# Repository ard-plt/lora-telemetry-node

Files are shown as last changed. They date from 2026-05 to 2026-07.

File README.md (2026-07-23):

# LoRa Telemetry Node

An end-to-end telemetry link that reads MAVLink 2 data from a Pixhawk over
UART, packs it into a compact binary frame, encrypts it, and relays it over
a long-range 868 MHz LoRa link to a ground station running QGroundControl.

```
[Pixhawk TELEM2] --UART MAVLink2--> [ESP32-S3 TX Node] --LoRa 868MHz--> [ESP32-S3 RX Node] --USB--> [QGroundControl]
```

The ESP32 does not read any sensors itself — Pixhawk is the only data
source. The TX node parses MAVLink, serializes + encrypts a fixed-size
packet, and transmits it over LoRa; the RX node decrypts and re-emits it
as MAVLink 2 over USB so QGroundControl sees a normal telemetry stream.

## LoRa Module

Both nodes use an **EBYTE E22-900T30D** (SX1262, 868 MHz, up to 30 dBm)
LoRa transceiver module, talking to the ESP32 over UART in the module's
Normal (transparent) mode.

| Parameter | Value |
|---|---|
| Frequency | 868.0 MHz |
| Spreading Factor | SF9 |
| Bandwidth | 125 kHz |
| Coding Rate | 4/5 |
| TX Power | 30 dBm |
| Air Data Rate | selectable, 0.3–62.5 kbps (see below) |

**Power warning:** the E22-900T30D draws up to ~500 mA while transmitting.
Do **not** power it from the ESP32's own 3.3 V regulator — use a dedicated
AMS1117-3.3 LDO (1 A rated), with a shared ground between the ESP32 and
the E22.

### Bridge Mode + Air Data Rate

Each node can run in one of two modes, selected (along with the LoRa air
data rate) from a web configuration panel rather than a physical switch:

- **BRIDGE_TRANSPARENT** — the node becomes a transparent UART bridge so
  Mission Planner can reach the Pixhawk directly through the LoRa link for
  parameter/calibration/waypoint work.
- **BRIDGE_COMPRESSED** — normal telemetry mode: TX parses → packs →
  encrypts → transmits; RX receives → decrypts → unpacks → re-emits
  MAVLink.

| Air Rate | UART Baud |
|---|---|
| 0.3 / 1.2 / 2.4 / 4.8 kbps | 9600 |
| 9.6 kbps | 19200 |
| 19.2 kbps | 38400 |
| 38.4 kbps | 57600 |
| 62.5 kbps | 115200 |

Holding the config button (GPIO9) for 3 seconds opens a WPA2-protected
Wi-Fi access point (`TUAV-TX-Config` / `TUAV-RX-Config`) with a captive
portal for selecting bridge mode, air rate, and Wi-Fi password. Changing
the mode/rate from the **RX** node automatically re-synchronizes the
**TX** node over the RF link itself — no need to configure both ends by
hand. See `CLAUDE.md` for the full protocol details.

## PCB

A complete KiCad 10 PCB design lives under [`hardware/pcb/`](hardware/pcb),
covering both nodes as a two-board stack:

- **`main`** — ESP32-S3-DevKitC-1 socket + power section (UBEC input →
  PTC fuse → reverse-polarity protection → a dedicated buck regulator
  that isolates the E22's transmit current pulses from the ESP32 rail).
  Identical design for both TX and RX; fabricate two copies.
- **`tx_rf`** / **`rx_rf`** — the E22-900T30D module plus node-specific
  connectors (TX: Pixhawk TELEM2 JST-GH; RX: SSD1306 OLED header), on a
  small board that plugs directly onto `main` via a 16-pin header/socket
  (`J4`), stacked so the assembly stays compact.

Each project folder includes the schematic, PCB layout, custom footprint/
symbol libraries, and ready-to-fabricate Gerber + drill files
(`gerbers/`). Signal-net routing is left for completion in the KiCad GUI;
net assignments are DRC-verified and the ratsnest will guide it.

| Board | Size |
|---|---|
| `main` | 50 × 71 mm |
| `tx_rf` / `rx_rf` | 50 × 60 mm |

## Hardware Overview

| Component | Model |
|---|---|
| MCU | ESP32-S3-WROOM-1 (via ESP32-S3-DevKitC-1), ×2 |
| LoRa module | EBYTE E22-900T30D (SX1262, 868 MHz, 30 dBm) |
| Pixhawk link | TELEM2 → ESP32 UART2, MAVLink 2, 57600 baud |
| Ground station link | RX node's native USB (USB-OTG), 57600 baud — no FT232 needed |
| OLED (RX only) | SSD1306 128×64, I2C |

## Pin Mapping

### TX Node (air)

| Signal | ESP32 Pin |
|---|---|
| E22 TXD | GPIO4 (UART1 RX) |
| E22 RXD | GPIO5 (UART1 TX) |
| E22 AUX | GPIO6 |
| E22 M0 | GPIO7 |
| E22 M1 | GPIO8 |
| Config button | GPIO9 |
| Pixhawk TELEM2 TX | GPIO16 (UART2 RX) |
| Pixhawk TELEM2 RX | GPIO17 (UART2 TX) |

### RX Node (ground)

| Signal | ESP32 Pin |
|---|---|
| E22 TXD | GPIO4 (UART1 RX) |
| E22 RXD | GPIO5 (UART1 TX) |
| E22 AUX | GPIO6 |
| E22 M0 | GPIO7 |
| E22 M1 | GPIO8 |
| Config button | GPIO9 |
| OLED SDA | GPIO11 |
| OLED SCL | GPIO12 |

E22 M0=LOW, M1=LOW selects Normal TX/RX mode (set automatically at boot).
The E22↔ESP32 UART baud follows the selected air data rate (see table
above); the Pixhawk and ground-station links stay fixed at 57600 baud
regardless of LoRa mode.

## Packet Format (40 bytes, plaintext)

| Offset | Len | Type | Field |
|---|---|---|---|
| 0 | 1 | uint8 | header (fixed 0xAD) |
| 1 | 1 | uint8 | seq_id |
| 2 | 4 | int32 | latitude (degE7) |
| 6 | 4 | int32 | longitude (degE7) |
| 10 | 4 | int32 | altitude_mm (MSL) |
| 14 | 2 | int16 | relative_alt_cm |
| 16 | 2 | int16 | groundspeed_cms |
| 18 | 2 | int16 | airspeed_cms |
| 20 | 2 | int16 | heading_cd |
| 22 | 2 | int16 | roll_cd |
| 24 | 2 | int16 | pitch_cd |
| 26 | 2 | int16 | yaw_cd |
| 28 | 2 | int16 | climb_rate_cms |
| 30 | 2 | uint16 | vbat_mv |
| 32 | 2 | int16 | current_da |
| 34 | 2 | uint16 | lidar_cm (0xFFFF = invalid) |
| 36 | 1 | uint8 | battery_pct |
| 37 | 1 | uint8 | flight_mode |
| 38 | 1 | uint8 | armed |
| 39 | 1 | uint8 | checksum (XOR of bytes 0–38) |

## Encryption

Telemetry is encrypted with AES-128-CTR (ESP32 hardware AES accelerator
via mbedTLS) before transmission: 40-byte plaintext → 40-byte ciphertext,
plus an 8-byte nonce (`seq_id` + low bytes of `millis()`) sent alongside
it. The key lives in `common/aes_config.h` as `AES_KEY` — the checked-in
value is a placeholder, **change it before any real deployment**, and
flash both nodes with the same key.

Separately, copy `common/secrets.h.example` to `common/secrets.h` and
fill in your own `WEB_CONFIG_SALT` (generate one with `openssl rand -hex
32`). This salt authenticates the HMAC on the RX→TX mode/rate sync
command over the RF link; `secrets.h` is gitignored and must never be
committed.

## Build & Flash

```bash
pip install platformio

# TX node
cd tx-node && pio run --target upload

# RX node
cd rx-node && pio run --target upload
```

## QGroundControl Setup

Application Settings → Comm Links → Add:
- Type: **Serial**
- Port: the RX node's COM / `ttyACM` port
- Baud rate: **57600**

See [`docs/qgc_setup.md`](docs/qgc_setup.md) for details and
[`docs/breadboard_wiring.md`](docs/breadboard_wiring.md) for a breadboard
wiring guide (or use the PCB design above instead).

## License

MIT

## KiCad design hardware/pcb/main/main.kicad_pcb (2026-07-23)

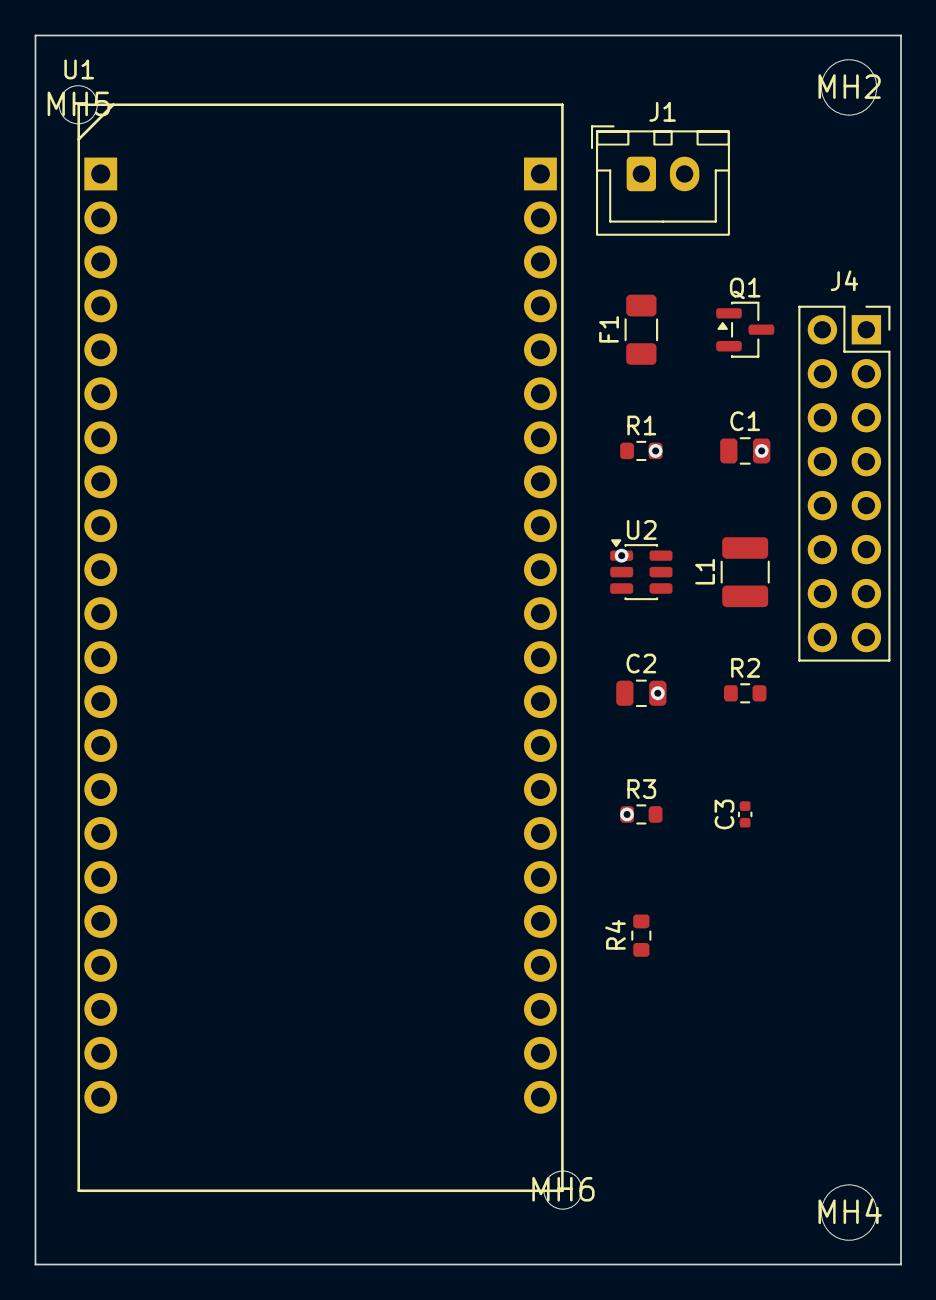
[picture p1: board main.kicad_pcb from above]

Board: 2 copper layers, 50.0 x 71.0 mm, 18 parts (0 on the bottom side), 22 nets, no tracks yet.

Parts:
C1, C2: 22uF; C_0805_2012Metric
C3: 100nF; C_0402_1005Metric
F1: PTC 1.1A; Fuse_1206_3216Metric
J1: VIN_UBEC; JST_XH_B2B-XH-A_1x02_P2.50mm_Vertical
J4: STACK_TO_RF; PinSocket_2x08_P2.54mm_Vertical
L1: 2.2uH; L_1210_3225Metric
MH2, MH4, MH5, MH6: (no value)
Q1: AO3401A; SOT-23
R1, R3: 10k; R_0603_1608Metric
R2: 56k; R_0603_1608Metric
R4: 100k; R_0603_1608Metric
U1: DevKitC-1; ESP32-S3-DevKitC-1_Socket_2x22_P2.54mm
U2: TPS563201; SOT-23-6

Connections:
+3V3: J4.4, U1.J1-1, U1.J1-2
CONFIG_BTN: J4.10, U1.J1-15
E22_AUX: J4.9, U1.J1-6
E22_M0: J4.7, U1.J1-7
E22_M1: J4.8, U1.J1-12
E22_RXD: J4.6, U1.J1-5
E22_SW: C3.2, L1.1, U2.2
E22_TXD: J4.5, U1.J1-4
E22_VCC: C2.1, J4.3, L1.2, R2.2
GND: C1.2, C2.2, J1.2, J4.1, J4.2, J4.16, R1.2, R3.1, U1.J1-22, U1.J3-1, U1.J3-21, U1.J3-22, U2.1
LED_CTRL: J4.11, U1.J3-5
unnamed: C3.1, U2.6
unnamed: R2.1, R3.2, U2.4
unnamed: R4.1, U2.5
OLED_SCL: J4.15, U1.J1-18
OLED_SDA: J4.14, U1.J1-17
PIXHAWK_RX: J4.13, U1.J1-9
PIXHAWK_TX: J4.12, U1.J1-10
Q1_GATE: Q1.1, R1.1
VIN_FUSED: F1.2, Q1.2
VIN_RAW: F1.1, J1.1
VSYS: C1.1, Q1.3, R4.2, U1.J1-21, U2.3

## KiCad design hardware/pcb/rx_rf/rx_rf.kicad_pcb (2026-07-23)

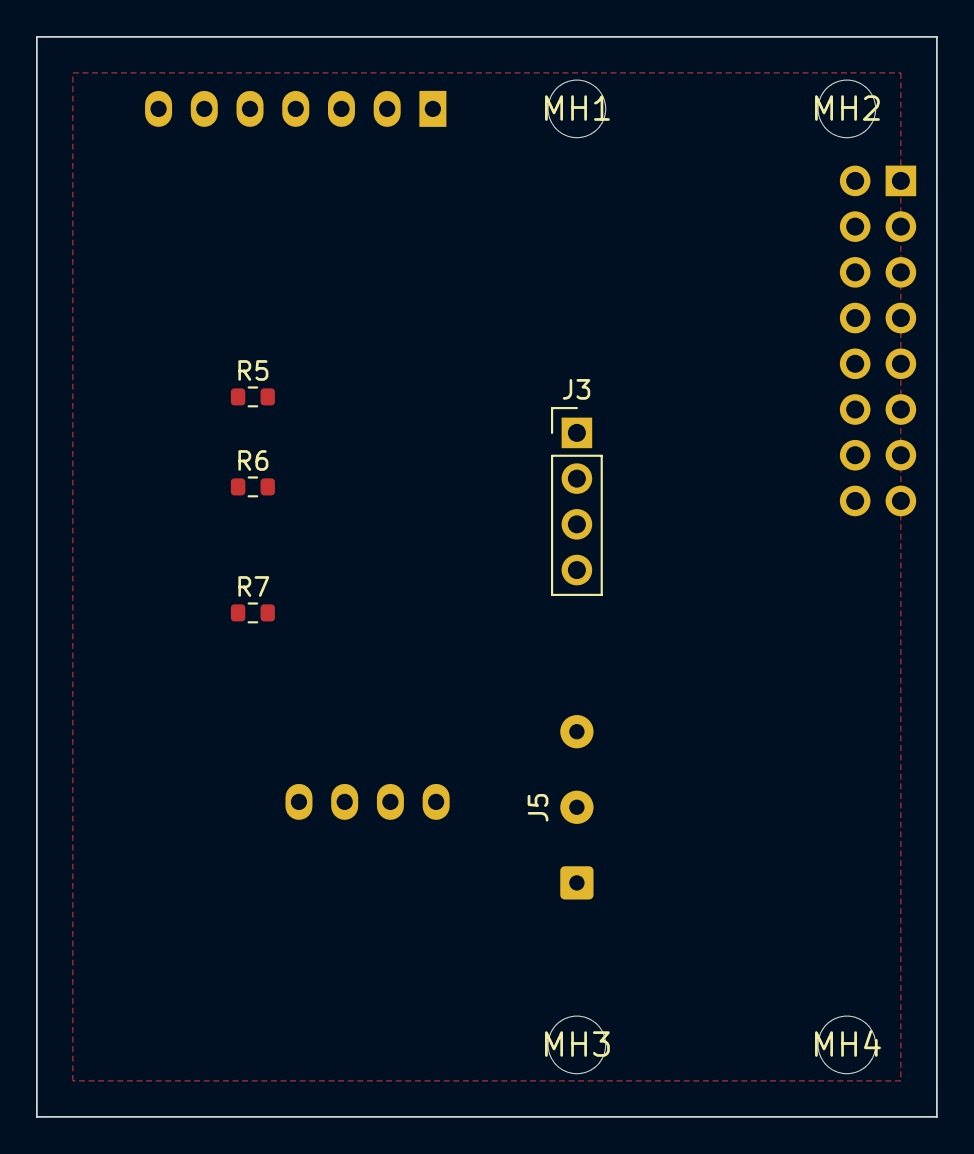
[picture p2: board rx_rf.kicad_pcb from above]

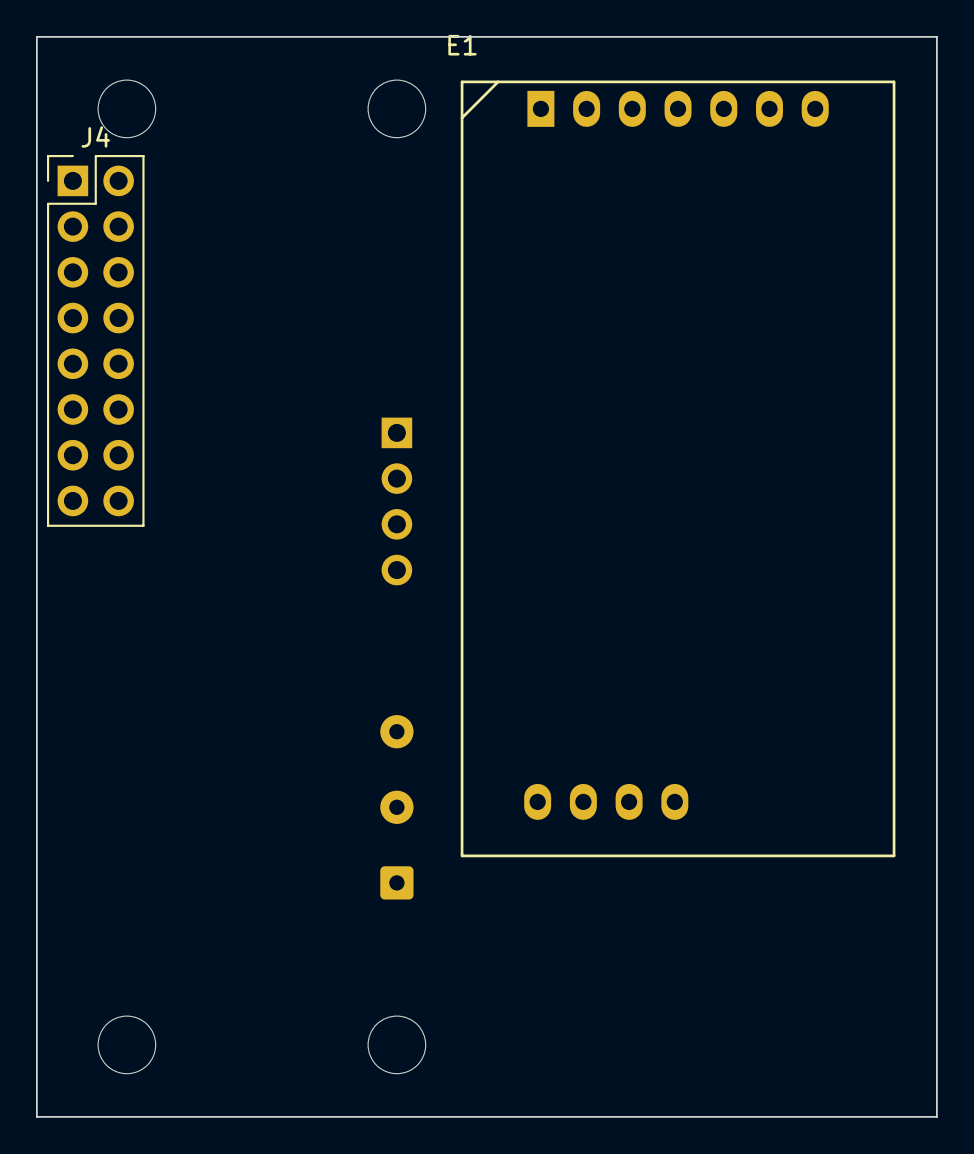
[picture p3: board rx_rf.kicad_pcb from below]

Board: 2 copper layers, 50.0 x 60.0 mm, 11 parts (2 on the bottom side), 13 nets, no tracks yet.

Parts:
E1: E22-900T30D
J3: OLED_SSD1306; PinHeader_1x04_P2.54mm_Vertical
J4: STACK_TO_MAIN; PinHeader_2x08_P2.54mm_Vertical
J5: BTN_LED_REMOTE; SolderWire-0.25sqmm_1x03_P4.2mm_D0.65mm_OD1.7mm
MH1, MH2, MH3, MH4: (no value)
R5, R6: 4.7k; R_0603_1608Metric
R7: 330R; R_0603_1608Metric

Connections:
+3V3: J3.1, J4.4, R5.1, R6.1
CONFIG_BTN: J4.10, J5.1
E22_AUX: E1.5, J4.9
E22_M0: E1.1, J4.7
E22_M1: E1.2, J4.8
E22_RXD: E1.3, J4.6
E22_TXD: E1.4, J4.5
E22_VCC: E1.6, J4.3
GND: E1.7, E1.8, E1.9, E1.10, E1.11, J3.2, J4.1, J4.2, J4.16, J5.2
LED_CTRL: J4.11, R7.1
unnamed: J5.3, R7.2
OLED_SCL: J3.4, J4.15, R6.2
OLED_SDA: J3.3, J4.14, R5.2

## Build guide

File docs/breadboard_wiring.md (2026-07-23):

# Breadboard Bağlantı Rehberi — ESP32 + E22-900T30D

## Önemli: E22 Güç Hattı

E22-900T30D TX anında **~500mA** akım çeker.
ESP32'nin 3.3V pininden BESLEME — E22 VCC direkt ESP32 3V3'e BAĞLAMA.

**Doğru güç yapısı:**
```
USB (5V) veya LiPo
    │
    ├── ESP32 5V (VIN pini) ──→ ESP32 dahili regülatör ──→ ESP32 çalışır
    │
    └── AMS1117-3.3 LDO (ayrı)
            │ IN: 5V
            │ OUT: 3.3V (1A kapasiteli)
            └──→ E22 VCC
                 (GND → ortak GND hattına)
```

Eğer AMS1117 yoksa geçici test için: ESP32 3V3 pininden besle ama
TX gücü maksimum **17 dBm'e düşür** (E22 register ile) — aksi halde
ESP32 regülatörü aşırı ısınır / reset atar.

---

## E22-900T30D Pin Düzeni

E22'nin modül üzerindeki pin sırası (tipik EBYTE layout, 2×8 pin):

```
       [ Anten ]
  ┌─────────────┐
  │  VCC   GND  │
  │  TXD   RXD  │
  │  AUX   M0   │
  │  M1    ...  │
  └─────────────┘
```

> **Datasheet kontrolü:** Elindeki E22'nin üzerindeki pin etiketlerine bak.
> TXD = E22'nin veri çıkışı → ESP32'nin RX pinine bağlanır.
> RXD = E22'nin veri girişi → ESP32'nin TX pinine bağlanır.

---

## Config Butonu + Web UI (KALİBRASYON / UZUN MENZİL)

Her iki node'da E22'nin çalışma modu artık fiziksel bir SPDT switch ile değil,
GPIO9'a bağlı **momentary bir buton** ve buradan açılan bir web arayüzü ile
seçiliyor. GPIO9 `INPUT_PULLUP` olarak ayarlı — harici direnç gerekmez, butonu
doğrudan GPIO9 ↔ GND arasına bağla (basınca kısa devre, bırakınca açık).

| Davranış | Sonuç |
|---|---|
| Normal açılış (buton basılı değil) | NVS'te (`Preferences`) en son kaydedilen mod otomatik uygulanır, WiFi kapalı, LoRa relay loop'u hemen çalışır |
| Buton 3sn basılı tutulur | `WiFi.softAP()` ile WPA2 şifreli config AP'si açılır, captive portal (DNSServer + WebServer) başlar |
| Web UI'de mod seçimi | E22 çalışma zamanında yeniden yapılandırılır (canlı test), NVS'e henüz yazılmaz |
| "Uçuşa Hazır / Kaydet ve Kapat" | Seçili mod NVS'e kaydedilir, AP kapanır, node normal moda döner |
| AP açıkken 5dk hiç istek gelmezse  | AP otomatik kapanır, normal moda döner (watchdog) |

| Mod (BridgeMode)  | Varsayılan E22 UART Baud | Varsayılan Air Rate |
|---|---|---|
| KALİBRASYON (BRIDGE_TRANSPARENT) | 115200 | 62.5kbps |
| UZUN MENZİL (BRIDGE_COMPRESSED)  | 9600 | 2.4kbps  |

KALİBRASYON modunda node transparan köprüye geçer (Mission Planner E22
üzerinden Pixhawk'a doğrudan erişir); UZUN MENZİL modu uçuş sırasında
kullanılacak asıl şifreli telemetri modudur. **Bridge mode (yukarıdaki
tablo) ve air rate artık BAĞIMSIZ seçilir** — web UI'daki air-rate
dropdown'undan 0.3/1.2/2.4/4.8/9.6/19.2/38.4/62.5 kbps arasından herhangi
biri, seçili bridge mode'dan bağımsız olarak seçilebilir; yukarıdaki tablo
sadece hiç değiştirilmemişse (ilk açılış) geçerli varsayılanı gösterir.
**TX ve RX'in konuşabilmesi için ikisinin de aynı air rate'te olması
gerekir** — bu LoRa'nın fiziksel katman kısıtıdır. RX'in web panelinden
yapılan değişiklikler artık TX'i RF üzerinden (ek kablolama YOK — aynı
E22↔E22 telemetri hattı üzerinden) otomatik senkronize eder: RX önce eski
profille bir komut gönderir, TX ACK'lerse RX de kendi profilini uygular; TX
yanıt vermezse (menzil dışı vb.) RX kendi modunu değiştirmez ve panelde
hata gösterir. Ayrıntı ve paket formatı: `common/sync_command.h`,
`rx-node/lib/sync_master/sync_master.h`, ana `CLAUDE.md`'deki **RX-Master
Mod/Rate Senkronizasyonu** bölümü. TX'in panelinden DOĞRUDAN yapılan bir
değişiklik bu mekanizmayı TETİKLEMEZ (RX'e senkronize edilmez). Profil
detayı: `common/lora_modes.h` (`BridgeMode`, `AirRate`,
`lora_build_profile`). Web config paneli detayı: `common/web_config.h` ve
ana `CLAUDE.md`'deki **Web Config Paneli** / **Air Data Rate** bölümleri.

E22 REG1 bit5 (RSSI ambient noise enable, `LORA_REG1_VALUE`) her iki node'da
da her zaman açık tutulur — RX node'un periyodik RSSI sorgusu (bkz. **Link
İstatistikleri & OLED**, aşağıda) bu bite bağımlıdır; TX'te bu bitin bir
etkisi yoktur (zararsız).

**Güvenlik notu:** Config AP'si sadece buton 3sn basılı tutulunca açılır ve
WPA2 ile şifrelidir. Fabrika varsayılan şifresi **tüm cihazlarda aynıdır**
(`tuav-loralink`) — kapalı/kontrollü ortamlarda (TEKNOFEST sahası gibi)
bilinçli olarak kabul edilmiş bir tercihtir. Açık/ticari dağıtımda web
panelindeki "AP Şifresini Değiştir" alanından (min 8 karakter) kendi
şifrenizi belirlemeniz ŞİDDETLE önerilir — aksi halde herkes aynı şifreyle
bağlanabilir; yeni şifre NVS'e yazılır ve bir sonraki AP açılışında geçerli
olur. `common/secrets.h`'deki `WEB_CONFIG_SALT` artık AP şifresiyle İLGİLİ
DEĞİLDİR — yalnızca **RX-Master Mod/Rate Senkronizasyonu** komut paketinin
HMAC doğrulamasında kullanılır (bkz. `CLAUDE.md`); yine de repoya commit
edilmez, kurulumdan önce `common/secrets.h.example`'ı kopyalayıp kendi
rastgele tuzunuzu üretin (`openssl rand -hex 32`). Uçuş/telemetri sırasında
WiFi tamamen kapalıdır. AP'nin kimlik doğrulaması/HTTPS/CSRF koruması yoktur;
tasarım fiziksel erişimi olan güvenilir bir operatör varsayar.

---

## Eşleşme LED'i (GPIO2, her iki node)

Her iki node'daki dahili LED (GPIO2) artık **eşleşme durumunu** gösterir —
eski "her paket alımında/gönderiminde kısa yanıp sönme" davranışı kaldırıldı:

| LED durumu | Anlamı |
|---|---|
| ~300ms periyotla yanıp sönüyor | Eşleşmemiş — karşı taraftan (RX: telemetri, TX: PING) son 3sn'de veri gelmedi, "aranıyor" |
| Sabit yanıyor | Eşleşik — link açık |

RX kendi eşleşme durumunu zaten bildiği telemetri akışından (son başarılı
paketin zamanı) çıkarır. TX'in bunu bilebilmesi için RX, ~1-1.5 saniyede bir
hafif bir `SYNC_TYPE_PING` paketi gönderir (ek donanım/kablolama YOK — aynı
E22↔E22 hattı üzerinden, RX-Master senkronizasyon komutlarıyla AYNI
HMAC-doğrulamalı mekanizmayı paylaşır); TX bunu pasif dinler, ACK göndermez.
Ayrıntı: `common/sync_command.h` (`SYNC_TYPE_PING`), `common/link_led.h`
(`LinkLed`), ana `CLAUDE.md`'deki **Eşleşme PING'i ve LED Durumu** bölümü.

---

## TX Node Bağlantıları

TX node: E22 + ESP32-S3 + Pixhawk (TELEM2)

> Not: ESP32-S3-WROOM-1'de GPIO 26-37 dahili Flash/PSRAM'a ayrılmış, kullanılamaz.

### E22 ↔ ESP32-S3 (UART1)

| E22 Pin | ESP32 Pin | Not |
|---|---|---|
| VCC | — | Ayrı AMS1117-3.3 çıkışına |
| GND | GND | Ortak GND hattı |
| TXD | GPIO4 | E22 çıkış → ESP32 UART1 RX  |
| RXD | GPIO5 | E22 giriş ← ESP32 UART1 TX  |
| AUX | GPIO6 | Modül hazır sinyali (INPUT)  |
| M0 | GPIO7 | Mod seçimi (OUTPUT) |
| M1 | GPIO8 | Mod seçimi (OUTPUT) |

### Config Butonu ↔ ESP32-S3

| Buton Pin | ESP32 Pin | Not |
|---|---|---|
| Bacak 1 | GPIO9 | INPUT_PULLUP — harici direnç yok |
| Bacak 2 | GND | Basınca kısa devre — 3sn basılı tutma web config AP'sini açar |

### Pixhawk TELEM2 ↔ ESP32-S3 (UART2)

| Pixhawk TELEM2 | ESP32 Pin | Not |
|---|---|---|
| TX | GPIO16 | Pixhawk çıkış → ESP32 RX |
| RX | GPIO17 | Pixhawk giriş ← ESP32 TX |
| GND | GND | Ortak GND — MUTLAKA bağla  |
| VCC (5V) | — | Bağlama, ESP32'yi ayrı besle|

---

## RX Node Bağlantıları

RX node: E22 + ESP32-S3 native USB

> Not: ESP32-S3-WROOM-1'de GPIO 26-37 dahili Flash/PSRAM'a ayrılmış, kullanılamaz.

### E22 ↔ ESP32-S3 (UART1)

| E22 Pin | ESP32 Pin | Not |
|---|---|---|
| VCC | — | Ayrı AMS1117-3.3 çıkışına |
| GND | GND | Ortak GND hattı |
| TXD | GPIO4 | E22 çıkış → ESP32 UART1 RX  |
| RXD | GPIO5 | E22 giriş ← ESP32 UART1 TX  |
| AUX | GPIO6 | Modül hazır sinyali (INPUT)  |
| M0 | GPIO7 | Mod seçimi (OUTPUT) |
| M1 | GPIO8 | Mod seçimi (OUTPUT) |

### Config Butonu ↔ ESP32-S3

| Buton Pin | ESP32 Pin | Not |
|---|---|---|
| Bacak 1 | GPIO9 | INPUT_PULLUP — harici direnç yok |
| Bacak 2 | GND | Basınca kısa devre — 3sn basılı tutma web config AP'sini açar |

### OLED (SSD1306 128x64 I2C) ↔ ESP32-S3 — sadece RX node

| OLED Pin | ESP32 Pin | Not |
|---|---|---|
| VCC | 3V3 | SSD1306 modülleri genelde 3.3V toleranslı (modülünün etiketini kontrol et) |
| GND | GND | Ortak GND hattı |
| SDA | GPIO11 | I2C veri hattı |
| SCL | GPIO12 | I2C saat hattı |

**Çakışma kontrolü:** GPIO11/12, RX node'da kullanımdaki diğer pinlerle
(2,4,5,6,7,8,9) çakışmıyor; ESP32-S3-WROOM-1'in Flash/PSRAM için ayırdığı
GPIO26-37 aralığının dışında; S3'ün strapping pinleri (GPIO0/3/45/46)
arasında da değil — I2C için güvenle kullanılabilir. I2C adresi çoğu 128x64
SSD1306 modülünde `0x3C`'tir (bazılarında `0x3D` — modülün üzerindeki
etikete/satıcı sayfasına bak, uymazsa `common/oled_display.h`'deki
`OLED_I2C_ADDR`'ı güncelle).

### ESP32-S3 native USB → PC (QGC çıkışı, birincil yöntem)

RX node `platformio.ini`'de `board = esp32s3box` kullanıyor; bu board tanımı
derleme zamanında `-DARDUINO_USB_CDC_ON_BOOT=1` bayrağını otomatik ekliyor.
Bu ayar aktifken kodda kullanılan `Serial` nesnesi **fiziksel UART0 pinlerine
(GPIO1/GPIO3) değil**, ESP32-S3'ün dahili USB-OTG çevre birimine (native USB
CDC) map olur. Yani PC bağlantısı doğrudan ESP32-S3'ün USB konnektöründen
yapılır — ayrı bir USB-UART köprü çipine gerek yoktur.

| Bağlantı | Not |
|---|---|
| ESP32-S3 USB portu | PC'ye doğrudan USB kablosuyla bağla |
| GND | USB kablosu üzerinden zaten ortak |

QGC/Mission Planner tarafında bu bağlantı PC'de sanal bir COM/ttyACM portu
olarak görünür; baud rate ayarı yine `GS_BAUD` (57600) ile eşleşmeli.

### (Opsiyonel/yedek) ESP32 ↔ FT232 USB-UART

Native USB portu kullanılamıyorsa (örn. debug sırasında `Serial` başka bir
amaçla meşgulse) yedek olarak harici FT232 üzerinden UART0 pinleri de
kullanılabilir — ancak bu artık birincil yöntem değildir ve `ARDUINO_USB_CDC_ON_BOOT=1`
aktifken `Serial.begin()` bu pinlere çıkmaz; UART0'a doğrudan erişmek için
koddan `Serial0` nesnesi kullanılmalıdır.

| ESP32 Pin | FT232 Pin | Not |
|---|---|---|
| GPIO1 (TX0) | RXD | Serial0 → FT232 giriş |
| GPIO3 (RX0) | TXD | (isteğe bağlı, tek yön yeterli) |
| GND | GND | Ortak GND |

---

## Breadboard Kurulum Sırası

1. **GND hattı:** Breadboard'un (-) rayını ESP32 GND, E22 GND (ve kullanılıyorsa FT232 GND) ile birleştir
2. **Güç:** AMS1117-3.3 çıkışını E22 VCC'ye bağla; ESP32'yi USB veya VIN'den besle
3. **M0/M1:** GPIO7 → M0, GPIO8 → M1 (kod modu değiştirirken otomatik sürer, pull-down direnci gerekmez)
4. **AUX:** GPIO6 → AUX (seri direnci yok, doğrudan bağla)
5. **UART:** TXD/RXD çapraz bağla (TX→RX, RX→TX)
6. **Config Butonu:** GPIO9 ↔ GND arasına momentary buton bağla (INPUT_PULLUP, harici direnç yok)
7. **(Sadece RX) OLED:** SDA→GPIO11, SCL→GPIO12, VCC→3V3, GND→GND
8. Programla, Serial monitörde `[LoRa] TX/RX hazir` mesajını bekle (RX'te OLED bağlıysa ekranda mod/RSSI/istatistik görünür)

---

## Kontrol Listesi

- [ ] E22 VCC ayrı LDO'dan besleniyor (ESP32 3V3'ten değil)
- [ ] GND hatları birleşik (ESP32 + E22 + LDO, FT232 kullanılıyorsa o da dahil)
- [ ] TXD/RXD çapraz bağlı (E22 TXD → ESP32 RX pini)
- [ ] M0, M1 doğru ESP32 pinlerine bağlı
- [ ] AUX bağlı (bağlanmazsa kod AUX timeout hatası verir)
- [ ] Config butonu GPIO9 ↔ GND arasına bağlı (momentary — sürekli kısa devre BIRAKMA, aksi halde her açılışta config AP'si tetiklenir)
- [ ] (Sadece RX) OLED SDA/SCL sırasıyla GPIO11/GPIO12'ye bağlı, VCC 3V3'ten besleniyor
- [ ] Anten E22'ye takılı (antensiz TX yapma — modül hasar görebilir)

---

## Beklenen Serial Çıktısı (başarılı kurulum)

**TX node:**
```
[LoRa] TX hazir | 868 MHz, 2.4kbps air rate
[MAVLink] Baslaniyor...
[TX] seq=1 gonderildi
[TX] seq=2 gonderildi
```

**RX node:**
```
# LoRa Telemetry RX Node starting...
# [LoRa] RX hazir | 868 MHz, 2.4kbps — dinleniyor...
# [RX] Paket alindi seq=1
```

OLED bağlıysa ekranda: bridge mode + air rate, `RSSI: -72 dBm` (+ sinyal
çubuğu), `Durum: BAGLI`/`ARANIYOR`, `Pkt:N Kayip:N`, `Bozuk:N Verim:%N`,
sağ üstte batarya voltajı görünür. OLED bağlı değilse/yanıt vermezse Serial'da
tek satırlık bir uyarı basılır (`# [OLED] Baslatilamadi...`) ve kod OLED'siz
çalışmaya devam eder — diğer işlevsellik etkilenmez.

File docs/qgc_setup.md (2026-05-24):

# QGroundControl Kurulum Rehberi

## Genel Bakış

RX node, LoRa'dan gelen şifreli paketi çözüp MAVLink 2 stream'e dönüştürür
ve USB-UART üzerinden PC'ye iletir. QGroundControl bu stream'i doğrudan
ArduPilot aracı olarak tanır.

```
[TX Node] --LoRa--> [RX Node] --USB (57600 baud)--> [PC: QGroundControl]
```

---

## 1. Donanım Bağlantısı

1. RX node'un **FT232 USB-UART** adaptörünü PC'ye tak
2. Linux'ta port: `/dev/ttyUSB0` (veya ttyUSB1, ttyACM0)
   Windows'ta port: `COMx` (Aygıt Yöneticisi'nden kontrol et)
3. Baud rate: **57600** (RX node `Serial.begin(57600)` ile başlatılıyor)

> **Not:** ESP32 USB'si değil, FT232 adaptörünün USB kablosu bağlanmalı.
> ESP32 USB'si sadece programlama/debug içindir.

---

## 2. QGroundControl Comm Link Ayarı

1. QGC'yi aç → sol üst **Q** logosuna tıkla → **Application Settings**
2. Sol menüden **Comm Links** seç
3. **Add** butonuna bas, şu değerleri gir:

| Alan | Değer |
|---|---|
| Name | LoRa RX Node |
| Type | Serial |
| Serial Port | `/dev/ttyUSB0` veya `COMx` |
| Baud Rate | 57600 |

4. **OK** → listede "LoRa RX Node" görünür
5. Üzerine tıkla → **Connect**

---

## 3. Beklenen Davranış

Bağlantı kurulduktan sonra QGC'de görünecekler:

| QGC Bileşeni | Kaynak MAVLink Mesajı | Güncelleme Hızı |
|---|---|---|
| Harita konumu | GLOBAL_POSITION_INT (#33)| 2 Hz (LoRa hızı)|
| HUD roll/pitch/yaw | ATTITUDE (#30) | 2 Hz |
| Airspeed, altitude | VFR_HUD (#74) | 2 Hz |
| Batarya göstergesi | SYS_STATUS (#1) | 2 Hz |
| Armed / uçuş modu  | HEARTBEAT (#0) | 1 Hz |

> **GPS kilidi:** QGC haritada konum göstermek için geçerli GPS koordinatı ister.
> Pixhawk GPS fix almadıysa harita güncellenmez; HUD ve batarya yine de çalışır.

---

## 4. Linux Port İzni (tek seferlik)

```bash
sudo usermod -aG dialout $USER
# Çıkış yapıp tekrar giriş yap
```

Veya geçici:
```bash
sudo chmod 666 /dev/ttyUSB0
```

---

## 5. Bağlantı Testi — Serial Monitor ile Doğrulama

QGC'ye geçmeden önce RX node'un MAVLink binary çıkardığını doğrula:

```bash
# Binary akışı gör (satırlar karmaşık görünür — bu normal, MAVLink binary)
cat /dev/ttyUSB0

# Veya python ile mesaj sayısını say
python3 -c "
import serial, time
s = serial.Serial('/dev/ttyUSB0', 57600, timeout=1)
count = 0
t = time.time()
while time.time() - t < 5:
    data = s.read(256)
    if data: count += len(data)
print(f'5 saniyede {count} byte alındı')
# Beklenen: ~500 byte/s (MAVLink mesajları @ 2Hz)
"
```

---

## 6. Sorun Giderme

| Belirti | Olası Neden | Çözüm |
|---|---|---|
| QGC "Waiting for Vehicle" | Yanlış port veya baud | Port ve baud rate'i kontrol et |
| QGC "Waiting for Vehicle" | TX node göndermiyordur | TX node Serial logunu kontrol et |
| Harita güncellenmez | GPS fix yok | Pixhawk GPS fix alana kadar bekle |
| Port listede görünmüyor | FT232 driver yok | `lsusb` ile FT232 tespit edildiğini doğrula |
| Binary çıkış yok | RX node LoRa paketi almıyor | LoRa frekans/SF parametrelerini kontrol et |

---

## 7. Sistem Parametreleri (Hatırlatma)

```
LoRa Frekans : 868.0 MHz
SF           : 9
Bandwidth    : 125 kHz
TX Power     : 30 dBm
Gönderim     : 2 Hz
MAVLink Baud : 57600
SysID        : 1  (ArduPilot autopilot taklidi)
CompID       : 1
```

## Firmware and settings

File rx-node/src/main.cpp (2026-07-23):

#include <Arduino.h>
#include "lora_rx.h"
#include "mavlink_tx.h"
#include "packet.h"
#include "lora_modes.h"
#include "web_config.h"
#include "oled_display.h"
#include "link_stats.h"
#include "sync_command.h"
#include "sync_master.h"
#include "link_led.h"

#define LED_PIN         2
#define CONFIG_BTN_PIN  9   // momentary buton: 3sn basili tutulunca web config AP'si acilir
#define PING_SEND_INTERVAL_MS 1200UL   // TX'e eslesme PING'i gonderim araligi (~1-1.5sn)

// LoraRx kendi içinde Serial1'i kullanıyor (lora_rx.cpp) - kalibrasyon modunda
// ham köprü için de aynı global Serial1'i kullanıyoruz, ikinci nesne açmıyoruz.
static LoraRx           lora;   // uzun menzil modunda paket almak için
static MavlinkTx        mav;
static WebConfigPortal  webConfig;
static OledDisplay      oled;
static LinkStatsTracker linkStats;
static SyncMaster       syncMaster; // RX-master mod/rate senkronizasyonu (bkz. sync_master.h)
static LinkLed          linkLed;    // eslesme durumuna gore yanip-soner/sabit yanar (bkz. common/link_led.h)

static BridgeMode currentBridge;
static AirRate    currentRate;
static uint32_t   lastHeartbeatMs = 0;
static uint32_t   lastPacketMs    = 0;
static uint32_t   lastPingSentMs  = 0;
static uint32_t   pkt_count       = 0;
static TelemetryPacket last_pkt = {};

// TX'e eslesme/LED durumu icin hafif bir PING gonderir - ACK beklenmez.
// BridgeMode'dan bagimsiz cagrilir: Serial1'e yazmak (E22 Normal modda)
// telemetriyi/senkron komutlarini bozmadan RF'e cikar (bkz. sync_command.h).
static void sendPingIfDue() {
    uint32_t now = millis();
    if (now - lastPingSentMs < PING_SEND_INTERVAL_MS) return;
    lastPingSentMs = now;

    SyncPacket ping;
    sync_build_ping(ping);
    // AUX LOW ise (E22 mesgul, ör. TX'in telemetrisiyle cakisma) bu tur
    // sessizce atlanir - bir sonraki PING_SEND_INTERVAL_MS'te tekrar denenir.
    lora_try_write(Serial1, LORA_AUX_PIN, (uint8_t*)&ping, sizeof(ping));
}

// Mevcut air rate'e göre E22'yi ve UART hızını yeniden ayarla. BridgeMode'un
// REG0 üzerinde etkisi yok (yalnızca loop()'un hangi dalını çalıştıracağını
// belirler) — o yüzden burada sadece currentRate kullanılır.
void applyProfile() {
    LoraProfile p = lora_build_profile(currentRate);
    Serial.printf("\n# [PROFIL] Bridge=%s Rate=%s\n", bridge_mode_name(currentBridge), p.name);

    bool ok = lora_apply_profile(Serial1, LORA_M0_PIN, LORA_M1_PIN, LORA_AUX_PIN, p);
    Serial1.updateBaudRate(p.uartBaud);

    if (!ok) Serial.println("# [UYARI] E22 config yaniti alinamadi");

    if (currentBridge == BRIDGE_TRANSPARENT) {
        Serial.println("# [MOD] Transparan kopru aktif - Mission Planner E22 uzerinden dogrudan konusuyor");
    } else {
        Serial.println("# [MOD] Sifreli telemetri cozme + QGC MAVLink sentezleme aktif");
    }
}

// ACK dogrulaninca cagrilir (SyncMaster icinden) - RX artik TX'in onayladigi
// profili kendi uzerinde de uygular. requestChange()'e verilen mode/rate ile
// ayni oldugu SyncMaster::handleIncoming() icinde zaten dogrulandi.
static void syncApplyCallback(BridgeMode mode, AirRate rate) {
    currentBridge = mode;
    currentRate   = rate;
    applyProfile();
}

// BRIDGE_TRANSPARENT dalinda sync_relay_with_filter()'e verilen handler - duz
// fonksiyon pointer gerektigi icin global syncMaster'a yonlendiren kucuk bir
// sarmalayici (main.cpp'deki diger callback'lerle ayni desen).
static void rxSyncPacketHandler(SyncPacketType type, BridgeMode mode, AirRate rate) {
    syncMaster.handleIncoming(type, mode, rate);
}

// ===== WebConfigPortal callback'leri =====
static BridgeMode wcGetMode() { return currentBridge; }

// ARTIK E22'yi HEMEN degistirmez - once TX'e senkronizasyon istegi gonderir
// (bkz. syncMaster.requestChange). currentBridge, yalnizca TX ACK'i
// dogrulaninca syncApplyCallback() icinde guncellenir.
static void wcSetMode(BridgeMode mode) {
    syncMaster.requestChange(mode, currentRate);
}

static AirRate wcGetAirRate() { return currentRate; }

static void wcSetAirRate(AirRate rate) {
    syncMaster.requestChange(currentBridge, rate);
}

static uint32_t wcGetPacketCount() { return pkt_count; }
static uint32_t wcGetLastEventAgoMs() { return millis() - lastPacketMs; }

// RX'e özgü link istatistikleri — OLED de AYNI linkStats/lora nesnelerini okur,
// hesaplama tek yerde (LinkStatsTracker + LoraRx::pollRssi) yapılır.
static void wcAppendExtraStatus(String& json) {
    json += ",\"rssi_dbm\":" + String(lora.getLastRssiDbm());
    json += ",\"rssi_valid\":" + String(lora.hasRssi() ? "true" : "false");
    json += ",\"rx_success_count\":" + String(linkStats.successCount());
    json += ",\"rx_lost_count\":" + String(linkStats.lostCount());
    json += ",\"rx_corrupt_count\":" + String(linkStats.corruptCount());
    json += ",\"link_efficiency_pct\":" + String(linkStats.efficiencyPct());
    if (const char* s = syncMaster.statusText()) {
        json += ",\"sync_status\":\"" + String(s) + "\"";
    }
}

void setup() {
    // Kalibrasyon modunda bu port Mission Planner'a HAM MAVLink taşıyacağı için
    // baud'u uzun menzil modundaki QGC beklentisiyle (GS_BAUD) aynı tutuyoruz;
    // Mission Planner'da COM port ayarını da GS_BAUD'da bırakabilirsiniz.
    Serial.begin(GS_BAUD);

    linkLed.begin(LED_PIN);
    pinMode(CONFIG_BTN_PIN, INPUT_PULLUP);
    pinMode(LORA_M0_PIN, OUTPUT);
    pinMode(LORA_M1_PIN, OUTPUT);
    pinMode(LORA_AUX_PIN, INPUT);

    Serial1.begin(9600, SERIAL_8N1, LORA_ESP_RX_PIN, LORA_ESP_TX_PIN);
    delay(100);

    lora.attachLinkStats(linkStats);
    syncMaster.begin(Serial1, LORA_AUX_PIN, syncApplyCallback);

    // Açılışta NVS'te kayıtlı son bridge mode + air rate'i uygula (ilk açılışta
    // varsayılan: UZUN MENZIL + o bridge mode'un varsayılan air rate'i)
    currentBridge = WebConfigPortal::loadSavedMode("rxcfg", BRIDGE_COMPRESSED);
    currentRate   = WebConfigPortal::loadSavedAirRate("rxcfg", default_air_rate_for(currentBridge));
    applyProfile();

    if (!oled.begin()) {
        Serial.println("# [OLED] Baslatilamadi (bagli degil mi? SDA=GPIO11 SCL=GPIO12) - ekran gosterimi devre disi");
    }

    WebConfigCallbacks cb;
    cb.apSsid                 = "TUAV-RX-Config";
    cb.nvsNamespace            = "rxcfg";
    cb.getMode                 = wcGetMode;
    cb.setMode                 = wcSetMode;
    cb.getAirRate              = wcGetAirRate;
    cb.setAirRate              = wcSetAirRate;
    cb.getPacketCount          = wcGetPacketCount;
    cb.getLastEventAgoMs       = wcGetLastEventAgoMs;
    cb.appendExtraStatusJson   = wcAppendExtraStatus;
    webConfig.begin(cb);
}

void loop() {
    // Buton 3sn basili tutulursa web config AP'sini acar; AP aciksa DNS/HTTP servis eder.
    // Non-blocking - LoRa/MAVLink akisini bloke etmez.
    webConfig.update(CONFIG_BTN_PIN);

    // Periyodik RSSI sorgusu - kendi icinde 1-2sn araligini/kisa timeout'unu
    // yonetir, non-blocking, mevcut telemetri dinlemeyi bloklamaz.
    lora.pollRssi();

    // RX-master mod/rate senkronizasyonu: tekrar gonderim + ACK timeout'unu
    // yonetir (Serial1'e yazar, ama okumaz) - BridgeMode'dan bagimsiz her
    // turda calismali (kullanici hangi moddayken senkron baslatirsa baslatsin).
    syncMaster.tick();

    // TX'e eslesme PING'i - BridgeMode'dan bagimsiz, kendi araligini kendi yonetir.
    sendPingIfDue();

    bool paired = (millis() - lastPacketMs) < WEB_CONFIG_PAIRED_WINDOW_MS;

    if (currentBridge == BRIDGE_TRANSPARENT) {
        // ---- TRANSPARAN KÖPRÜ: PC/Mission Planner (Serial) <-> E22 ham MAVLink ----
        while (Serial.available()) Serial1.write(Serial.read());
        // TX'ten gelen ACK'i (varsa) yakalayip PC'ye sizdirmadan tuketir; geri
        // kalan her seyi (ham MAVLink) oldugu gibi Serial'e iletir - bkz.
        // sync_command.h dosya-ustu yorum (MAVLink kendi kendini senkronize eder).
        sync_relay_with_filter(Serial1, Serial, rxSyncPacketHandler);

    } else {
        // Senkronizasyon aktifse ACK'i Serial1'den ara - lora.update()'ten ONCE,
        // ki bir ACK paketi 48-byte'lik telemetri okumasiyla yanlislikla
        // karismasin (bkz. sync_command.h / sync_master.h risk analizi).
        syncMaster.scanCompressed();

        // ---- UZUN MENZİL: al -> sifre coz -> deserialize -> QGC'ye MAVLink olarak yaz ----
        TelemetryPacket pkt;
        if (lora.update(&pkt)) {
            last_pkt = pkt;
            pkt_count++;
            lastPacketMs = millis();
            paired = true;

            mav.send_telemetry(pkt);
        }

        uint32_t now = millis();
        if (now - lastHeartbeatMs >= 1000) {
            lastHeartbeatMs = now;
            mav.send_heartbeat(last_pkt);
        }
    }

    // Eslesme durumuna gore LED: eslesmemisken yanip soner, eslesince sabit yanar
    // (bkz. common/link_led.h) - non-blocking, ayni "paired" OLED'de de kullanilir.
    linkLed.update(paired);

    OledStatusData disp;
    disp.bridgeModeName = bridge_mode_oled_label(currentBridge);
    disp.airRateName    = air_rate_name(currentRate);
    disp.rssiValid      = lora.hasRssi();
    disp.rssiDbm        = lora.getLastRssiDbm();
    disp.paired         = paired;
    disp.packetCount    = pkt_count;
    disp.lostCount      = linkStats.lostCount();
    disp.corruptCount   = linkStats.corruptCount();
    disp.efficiencyPct  = linkStats.efficiencyPct();
    disp.vbatValid      = (last_pkt.header == PACKET_HEADER); // henuz paket gelmediyse gecersiz
    disp.vbatMv         = last_pkt.vbat_mv;
    oled.update(disp);
}

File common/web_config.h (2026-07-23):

#pragma once
#include <Arduino.h>
#include <WiFi.h>
#include <WebServer.h>
#include <DNSServer.h>
#include <Preferences.h>
#include "lora_modes.h"

// ============================================================================
// Web tabanlı config paneli — GPIO9'daki momentary butonu 3sn basılı tutunca
// açılan WiFi AP + captive portal üzerinden mod seçimi (KALİBRASYON/UZUN MENZİL)
// ve canlı istatistik gösterimi.
//
// TX ve RX node aynı modülü kullanır; farklılaşan kısımlar (batarya voltajı,
// RX'in link istatistikleri vb.) WebConfigCallbacks üzerinden main.cpp'den
// enjekte edilir. setMode/setAirRate callback'leri main.cpp'deki applyProfile()
// benzeri fonksiyonu tetikler — BridgeMode ve AirRate birbirinden bağımsız
// seçilir (bkz. lora_modes.h).
//
// NOT: common/ her iki projeye -I../common ile header-only dahil edilir
// (packet.h, lora_modes.h ile aynı desen) — bu yüzden ayrı bir .cpp yok,
// tüm gövdeler in-class (dolayısıyla implicit inline) tanımlı.
// ============================================================================

#define WEB_CONFIG_BUTTON_HOLD_MS    3000UL              // butonu bu kadar basılı tutunca AP açılır
#define WEB_CONFIG_AP_TIMEOUT_MS     (5UL * 60UL * 1000UL) // 5 dk hareketsizlikte AP kapanır
#define WEB_CONFIG_PAIRED_WINDOW_MS  3000UL              // son paket/gönderim bu süreden yeniyse "bagli"
#define WEB_CONFIG_CLOSE_DELAY_MS    800UL               // save_close yanıtının client'a ulaşması için gecikme

// Fabrika varsayılan AP şifresi — TÜM cihazlarda AYNI (eski MAC-türetilmiş
// HMAC şifre sistemi kaldırıldı, bkz. CLAUDE.md güvenlik notu: kapalı/
// kontrollü ortamlarda kabul edilebilir bir tercih; açık dağıtımda operatör
// web panelinden değiştirmeli). WPA2 alt sınırı 8 karakterdir.
#define WEB_CONFIG_DEFAULT_AP_PASSWORD "tuav-loralink"
#define WEB_CONFIG_AP_PW_MIN_LEN        8

// Tüm alanlar zorunlu — appendExtraStatusJson hariç (NULL verilebilir).
struct WebConfigCallbacks {
    const char* apSsid;          // örn. "TUAV-TX-Config"
    const char* nvsNamespace;    // örn. "txcfg" / "rxcfg" (Preferences namespace, <=15 char)

    BridgeMode (*getMode)();                 // mevcut bridge mode'u döndürür
    void       (*setMode)(BridgeMode mode);  // canlı uygular (applyProfile), NVS'e YAZMAZ

    // AirRate, BridgeMode'dan BAĞIMSIZ seçilir (bkz. lora_modes.h) ama aynı
    // lora_apply_profile() çağrısını tetikler — setMode/setAirRate ikisi de
    // "canlı uygula, NVS'e yazma" sözleşmesini paylaşır.
    AirRate (*getAirRate)();
    void    (*setAirRate)(AirRate rate);

    uint32_t (*getPacketCount)();      // TX: gönderilen, RX: alınan paket sayısı
    uint32_t (*getLastEventAgoMs)();   // son gönderim/alım üzerinden geçen ms

    // /status JSON'una ham alan ekler, örn: ",\"vbat_mv\":12345" — NULL olabilir
    void (*appendExtraStatusJson)(String& json);
};

class WebConfigPortal {
public:
    // Callback setini kaydeder. AP henüz AÇILMAZ — buton basılı tutulana kadar bekler.
    void begin(const WebConfigCallbacks& cb) {
        _cb = cb;
        _apPassword = loadApPassword(_cb.nvsNamespace);
        Serial.printf("[WebConfig] Hazir. Config'e girmek icin butonu %lus basili tut. (AP sifresi: %s)\n",
                      WEB_CONFIG_BUTTON_HOLD_MS / 1000UL, _apPassword.c_str());
    }

    // loop() içinde HER iterasyonda çağrılmalı. delay() KULLANMAZ:
    //  - AP kapalıyken: sadece buton basılı tutma süresini ölçer
    //  - AP açıkken: DNS + HTTP isteklerini servis eder, 5dk timeout'u kontrol eder
    void update(int buttonPin) {
        bool pressed = (digitalRead(buttonPin) == LOW); // INPUT_PULLUP varsayımı

        if (!_active) {
            if (pressed) {
                if (!_pressing) {
                    _pressing = true;
                    _pressStartMs = millis();
                } else if (millis() - _pressStartMs >= WEB_CONFIG_BUTTON_HOLD_MS) {
                    _pressing = false;
                    _startAP();
                }
            } else {
                _pressing = false;
            }
            return;
        }

        // AP aktif — non-blocking servis
        _dns.processNextRequest();
        _server.handleClient();

        if (_closePending && millis() >= _closeAtMs) {
            _closePending = false;
            _stopAP();
            return;
        }

        if (millis() - _lastActivityMs > WEB_CONFIG_AP_TIMEOUT_MS) {
            Serial.println("[WebConfig] 5 dk hareketsizlik - AP kapatiliyor, normal moda donuluyor");
            _stopAP();
        }
    }

    bool isActive() const { return _active; }
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

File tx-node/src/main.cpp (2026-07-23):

#include <Arduino.h>
#include "lora_tx.h"
#include "mavlink_reader.h"
#include "crypto.h"
#include "packet.h"
#include "lora_modes.h"
#include "web_config.h"
#include "sync_command.h"
#include "link_led.h"

#define LED_PIN         2
#define CONFIG_BTN_PIN  9   // momentary buton: 3sn basili tutulunca web config AP'si acilir

// NOT: MavlinkReader kendi içinde Serial2'yi kullanıyor (mavlink_reader.cpp).
// LoraTx de kendi içinde Serial1'i kullanıyor (lora_tx.cpp). Aynı UART'a
// ikinci bir HardwareSerial nesnesiyle erişmiyoruz - çakışma olur. Kalibrasyon
// modunda E22'ye ham bayt yazmak için de doğrudan global Serial1'i kullanıyoruz.

static LoraTx         lora;   // uzun menzil modunda paket göndermek için
static MavlinkReader  mav;
static WebConfigPortal webConfig;
static LinkLed        linkLed;    // eslesme durumuna gore yanip-soner/sabit yanar (bkz. common/link_led.h)

static BridgeMode currentBridge;
static AirRate    currentRate;
static uint32_t   lastSendMs         = 0;
static uint32_t   lastPingReceivedMs = 0; // RX'ten son SYNC_TYPE_PING'in alindigi an - eslesme/LED icin
static uint8_t    seq                = 0;

// Mevcut air rate'e göre E22'yi ve UART hızını yeniden ayarla. BridgeMode'un
// REG0 üzerinde etkisi yok (yalnızca loop()'un hangi dalını çalıştıracağını
// belirler) — o yüzden burada sadece currentRate kullanılır.
void applyProfile() {
    LoraProfile p = lora_build_profile(currentRate);
    Serial.printf("\n[PROFIL] Bridge=%s Rate=%s\n", bridge_mode_name(currentBridge), p.name);

    bool ok = lora_apply_profile(Serial1, LORA_M0_PIN, LORA_M1_PIN, LORA_AUX_PIN, p);
    Serial1.updateBaudRate(p.uartBaud);

    if (!ok) Serial.println("[UYARI] E22 config yaniti alinamadi, modul zaten ayarli olabilir");

    if (currentBridge == BRIDGE_TRANSPARENT) {
        Serial.println("[MOD] Transparan kopru aktif - Mission Planner tam erisim");
    } else {
        Serial.println("[MOD] Sikistirilmis+sifreli telemetri aktif");
    }
}

// ===== WebConfigPortal callback'leri =====
static BridgeMode wcGetMode() { return currentBridge; }

static void wcSetMode(BridgeMode mode) {
    currentBridge = mode;
    applyProfile();
}

static AirRate wcGetAirRate() { return currentRate; }

static void wcSetAirRate(AirRate rate) {
    currentRate = rate;
    applyProfile();
}

static uint32_t wcGetPacketCount() { return seq; }
static uint32_t wcGetLastEventAgoMs() { return millis() - lastSendMs; }

// Pixhawk'tan okunan batarya voltajını /status JSON'una ekler
static void wcAppendExtraStatus(String& json) {
    json += ",\"vbat_mv\":" + String(mav.getData().vbat_mv);
}

// RX-master senkronizasyonu: RX'ten gecerli (magic+HMAC dogrulanmis) bir
// SYNC_TYPE_CMD alindiginda cagrilir. ONCE ACK'i MEVCUT (henuz degismemis)
// profille gonderiyoruz - RX hala eski air rate/REG0'da dinlerken ACK'i
// alabilsin diye. Sira TERSI olsaydi (once profili degistirip sonra ACK
// gondermek) air-rate degisen senkronizasyonlarda ACK, RX'in artik dinlemedigi
// bir REG0/baud'da gonderilecegi icin HICBIR ZAMAN ulasmazdi (bkz.
// rx-node/lib/sync_master/sync_master.h ustundeki ayni aciklama).
static void txHandleSyncCommand(BridgeMode mode, AirRate rate) {
    SyncPacket ack;
    sync_build_packet(SYNC_TYPE_ACK, mode, rate, ack);
    Serial1.write((uint8_t*)&ack, sizeof(ack));
    Serial1.flush();

    Serial.printf("[SYNC] RX'ten komut alindi: Bridge=%s Rate=%s - ACK gonderildi, profil uygulaniyor\n",
                  bridge_mode_name(mode), air_rate_name(rate));

    currentBridge = mode;
    currentRate   = rate;
    applyProfile();
}

// sync_scan()/sync_relay_with_filter() duz fonksiyon pointer bekliyor - RX'ten
// gelen SYNC_TYPE_CMD ve SYNC_TYPE_PING'i isler (ayni HMAC dogrulamali
// mekanizmayi paylasirlar, bkz. sync_command.h), kendi urettigimiz
// SYNC_TYPE_ACK'i (normalde bu yonde hic gelmez ama savunmaci olsun diye) yoksayar.
static void txSyncPacketHandler(SyncPacketType type, BridgeMode mode, AirRate rate) {
    if (type == SYNC_TYPE_PING) {
        lastPingReceivedMs = millis(); // eslesme/LED durumu icin - ACK gerekmez
        return;
    }
    if (type != SYNC_TYPE_CMD) return;
    txHandleSyncCommand(mode, rate);
}

void setup() {
    Serial.begin(115200);

    linkLed.begin(LED_PIN);
    pinMode(CONFIG_BTN_PIN, INPUT_PULLUP);
    pinMode(LORA_M0_PIN, OUTPUT);
    pinMode(LORA_M1_PIN, OUTPUT);
    pinMode(LORA_AUX_PIN, INPUT);

    // Pixhawk TELEM2 -> Serial2 (mav.begin() bunu içeride başlatıyor)
    mav.begin();

    // E22 UART'ı başlat (başlangıç hızı önemsiz, applyMode hemen düzeltecek)
    Serial1.begin(9600, SERIAL_8N1, LORA_ESP_RX_PIN, LORA_ESP_TX_PIN);
    delay(100);

    // Açılışta NVS'te kayıtlı son bridge mode + air rate'i uygula (ilk açılışta
    // varsayılan: UZUN MENZIL + o bridge mode'un varsayılan air rate'i)
    currentBridge = WebConfigPortal::loadSavedMode("txcfg", BRIDGE_COMPRESSED);
    currentRate   = WebConfigPortal::loadSavedAirRate("txcfg", default_air_rate_for(currentBridge));
    applyProfile();

    WebConfigCallbacks cb;
    cb.apSsid                 = "TUAV-TX-Config";
    cb.nvsNamespace            = "txcfg";
    cb.getMode                 = wcGetMode;
    cb.setMode                 = wcSetMode;
    cb.getAirRate              = wcGetAirRate;
    cb.setAirRate              = wcSetAirRate;
    cb.getPacketCount          = wcGetPacketCount;
    cb.getLastEventAgoMs       = wcGetLastEventAgoMs;
    cb.appendExtraStatusJson   = wcAppendExtraStatus;
    webConfig.begin(cb);
}
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

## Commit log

2026-05-24 feat: LoRa telemetry node — aşama 1-6 tamamlandı
    TX node: MAVLink2 parse, AES-128-CTR şifreleme, E22 UART LoRa TX (2 Hz)
    RX node: LoRa RX, decrypt, QGroundControl MAVLink çıkışı (57600 baud)
    common: TelemetryPacket (40 byte), AES nonce/IV yardımcıları
    tools: MAVLink simülatörü ve loopback test scriptleri
2026-07-23 feat: web config paneli, RX-master senkronizasyon, link istatistikleri ve OLED eklendi
    - GPIO9 config butonu + captive portal ile BridgeMode/AirRate/AP şifresi
    web arayüzünden yapılandırılabiliyor (common/web_config.h)
    - RX, mod/rate değişikliğinde TX'i RF üzerinden otomatik senkronize ediyor
    (common/sync_command.h, rx-node/lib/sync_master)
    - Eşleşme PING'i + paylaşılan LED durum mantığı (common/link_led.h)
    - RX tarafında link istatistikleri (kayıp/bozuk paket, verimlilik) ve
    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
2026-07-23 feat: KiCad PCB tasarımı eklendi (main + tx_rf + rx_rf)
    İki katlı stack mimarisi: main (DevKitC-1 + güç bloğu, TX ve RX için ortak
    tasarım) + tx_rf/rx_rf (E22-900T30D + node'a özel konnektörler), J4
    üzerinden board-to-board bağlanıyor. E22 ve J4 arka yüzde, board boyutları
    maliyet için küçültüldü (main 55x71mm, RF board'lar 50x60mm).
    İçerik: şematikler, custom footprint/sembol kütüphaneleri, PCB layout'ları
    (placement + GND pour, sinyal routing GUI'de tamamlanacak), Gerber + delik
    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
    [e22_rf.kicad_sch, esp32.kicad_sch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]
2026-07-23 chore: KiCad kilit dosyalarını git takibinden çıkar
    .kicad_pro.lck dosyaları KiCad'in kendi geçici kilit dosyaları,
    yanlışlıkla commit'e girmişler.
2026-07-23 docs: README İngilizce'ye çevrildi, LoRa modülü ve PCB bölümleri eklendi
